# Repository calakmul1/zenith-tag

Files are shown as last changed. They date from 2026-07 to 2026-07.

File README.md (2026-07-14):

# Zenith Tag - NFC Flight Altitude Logger

Zenith Tag is a compact embedded altitude logger built around the NXP NHS3100 and Bosch BMP388.
It captures relative max flight altitude from barometric pressure and writes the result as an NFC URI record, so the value can be read by a phone with no wired interface.

<table align="center">
	<tr>
		<td align="center" valign="middle" width="74%">
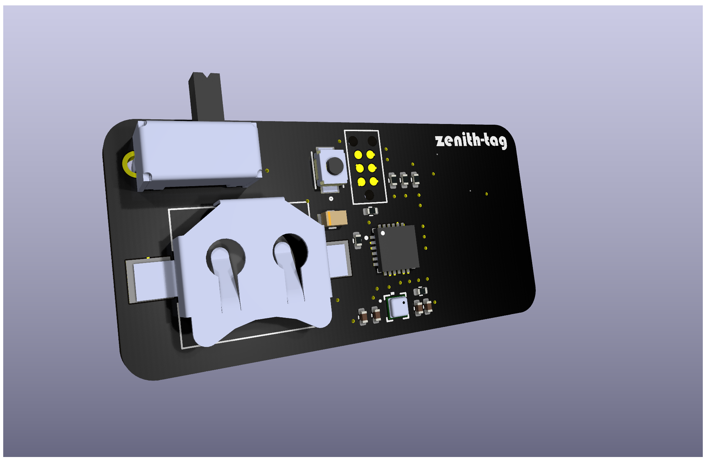
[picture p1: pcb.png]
PCB
			
		</td>
		<td align="center" valign="middle" width="26%">
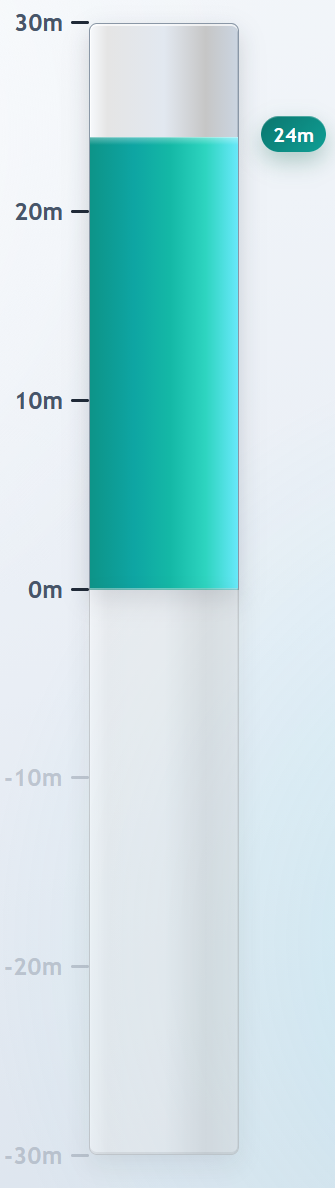
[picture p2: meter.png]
Altitude meter UI
			
		</td>
	</tr>
	<tr>
		<td align="center"><sub>PCB Layout</sub></td>
		<td align="center"><sub>Altitude Meter UI</sub></td>
	</tr>
</table>

## What This Repository Contains

This repository is split into three main parts:

- `hw/`: KiCad design files, custom libraries, 3D models, and datasheets
- `sw/`: NHS3100 firmware project (MCUXpresso style) and source modules
- `web/`: Vue 3 web app served from the NFC URI that visualises the recorded altitude

## High-Level Features

- BMP388 pressure and temperature acquisition over I2C
- Full BMP388 calibration and compensation implementation in firmware
- Relative altitude computation using barometric equation
- Push-button controlled measurement session
- LED status signaling (idle, actively measuring, and error indication)
- NFC Type-2 compatible NDEF URI payload written to NHS3100 shared memory
- Web app landing page that parses the height query parameter and renders an animated altitude bar

## Repository Structure

### Hardware (`hw/`)

- Main KiCad project files:
	- `hw/hw.kicad_sch`
	- `hw/hw.kicad_pcb`
	- `hw/hw.kicad_pro`
- Custom part libraries:
	- `hw/footprints/` and `hw/hw.pretty/` for footprint definitions
	- `hw/symbols/` for custom symbol definitions
	- `hw/models/` for STEP 3D models
- Engineering references:
	- `hw/datasheets/` for component PDFs and reference image files
	- `hw/calculations/NFC-Antenna-Calculation.xlsx` for antenna-related design calculations

### Firmware (`sw/`)

- Application source tree: `sw/src/`
- Core application entry point: `sw/src/main.c`
- Board and low-level init:
	- `sw/src/board/inc/board.h`
	- `sw/src/board/src/board.c`
- Functional components:
	- `sw/src/components/button/`
	- `sw/src/components/led/`
	- `sw/src/components/pressure/`
	- `sw/src/components/nfc/`
- Device/library code:
	- `sw/src/lib/lib_chip_nss/`
	- `sw/src/lib/startup/`

### Web App (`web/`)

A Vite + Vue 3 single-page app hosted at the NFC URI target.

- Entry point: `web/src/App.vue`
- Reads the `height` query parameter from the URL (e.g. `?height=12.34`)
- Renders an animated vertical bar showing the recorded altitude, clamped to ±30 m
- Styled with Bulma

To run locally:

```sh
cd web
npm install
npm run dev
```

To build for production:

```sh
npm run build
```

## Firmware Behavior

The main loop in `sw/src/main.c` follows this sequence:

1. Initialize board/peripherals and BMP388.
2. Wait for button press to start a measurement session.
3. Collect a short pre-takeoff pressure baseline (`PRE_TAKEOFF_MEASUREMENTS`).
4. Repeatedly sample pressure while session is active, tracking the minimum pressure reached.
5. End session with a second button press.
6. Compute signed relative altitude from both `pressure_min` and `pressure_max` versus baseline pressure, choose the larger magnitude, then apply a `-0.50 m` offset.
7. Store the measured value over NFC as a URI query parameter: `https://example.com/?height=<value>`.

Current default timing constants are defined in `sw/src/config.h`:

- Debounce: 5 ms
- Measurement interval: 20 ms
- LED toggle during active measurement: 500 ms
- Baseline sample count: 10

## Hardware/Firmware Interface Summary

- MCU: NXP NHS3100 (integrated NFC + Cortex-M0+)
- Pressure sensor: Bosch BMP388 on I2C address `0x77`
- Key pin usage in firmware:
	- `PIO0_1`: button input
	- `PIO0_2`: status LED output
	- `PIO0_4`: I2C SCL
	- `PIO0_5`: I2C SDA

## NFC Output Format

The NFC module (`sw/src/components/nfc/nfc.c`) writes a compact NDEF URI record into NHS3100 NFC shared memory.
The payload encodes a URL in this form: `https://example.com/?height=<value>`.

Example payload:

`https://example.com/?height=12.34`

## Build and Flash Notes

This project is structured like an MCUXpresso/Eclipse embedded project.

- Recommended workflow:
	- Import the `sw/` project into MCUXpresso IDE
	- Build using IDE-managed toolchain/configuration
	- Program/debug using LinkServer and the provided launch configuration
- Command-line makefiles are auto-generated and may contain absolute machine-specific paths in linker/library references.

## Included References

- Component datasheets and design references: `hw/datasheets/`

## Typical Use

1. Manufacture the PCB.
2. Configure GUI_BASE_URL in `config.h` with the URL of the web application that should open after the NFC tag is scanned.
3. Build and flash the firmware to the NHS3100 board.
4. Power on the tag and wait for idle-ready indication.
5. Press the button to start logging.
6. Press the button again to stop logging.
7. Tap a phone to the NFC antenna area — the phone opens the stored URI in a browser.
8. The web app reads the `height` query parameter and displays the recorded altitude.

---

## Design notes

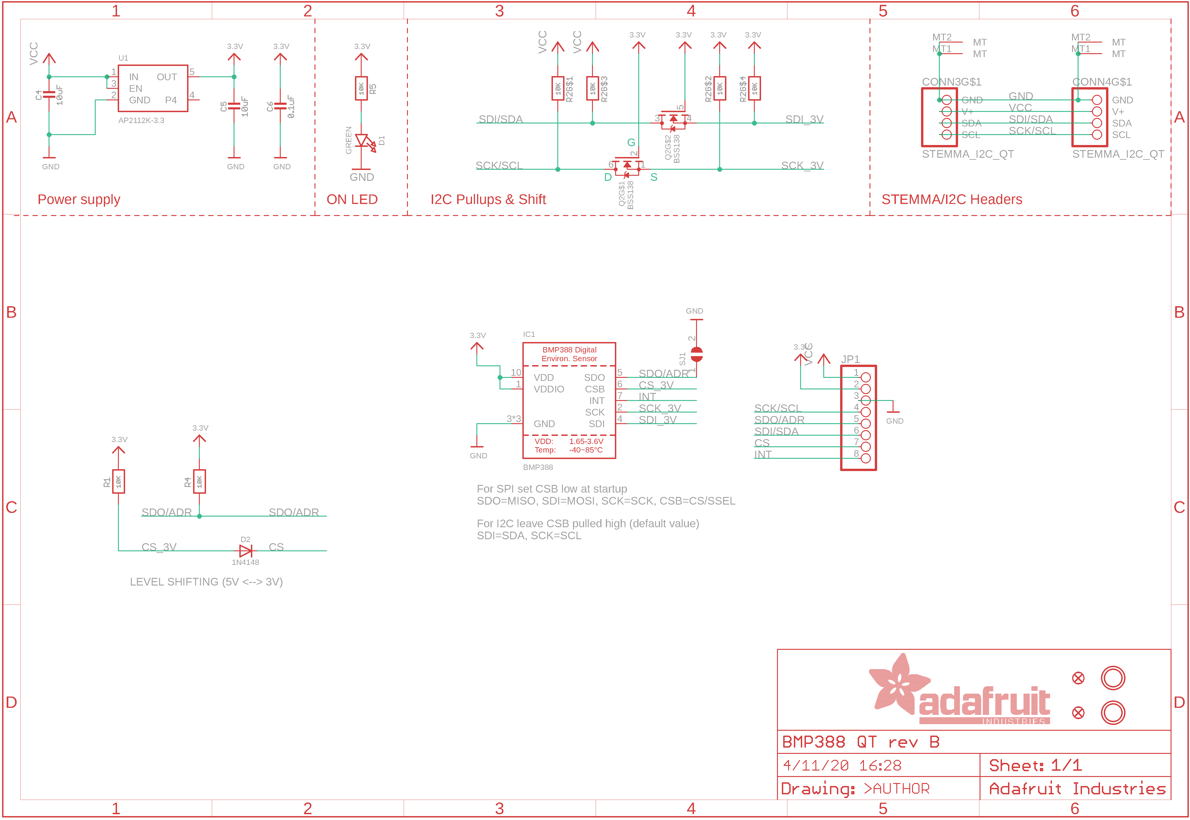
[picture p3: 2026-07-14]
hw/datasheets/sensors_BMP388_STEMMA_sch.png

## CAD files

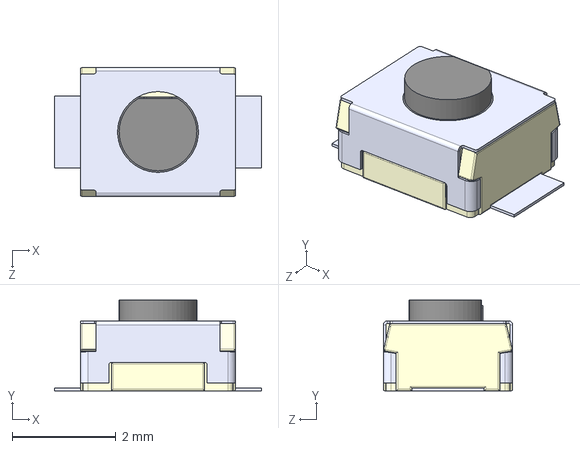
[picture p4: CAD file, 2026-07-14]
hw/models/B3U-1000P--3DModel-STEP-56544.STEP
4.00 x 1.75 x 2.50 mm

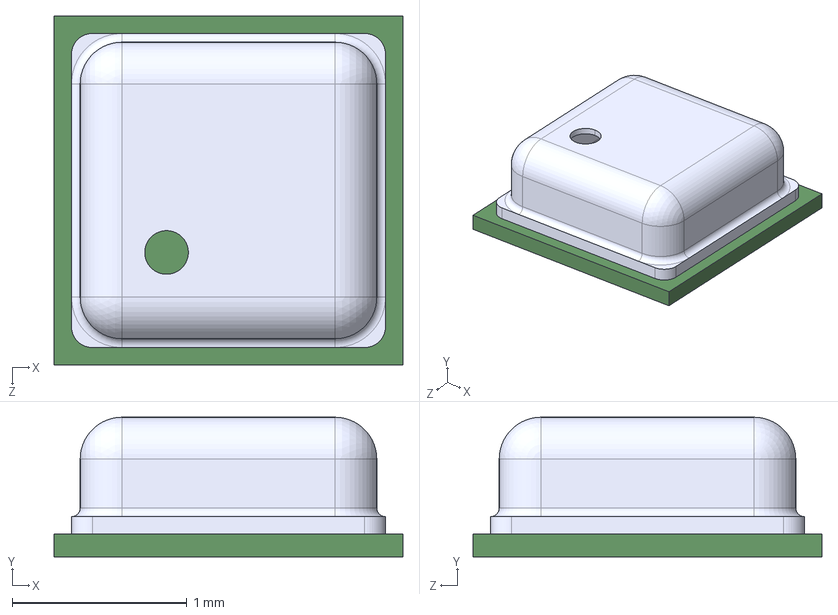
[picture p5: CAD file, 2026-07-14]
hw/models/BMP388--3DModel-STEP-56544.STEP
2.00 x 0.8 x 2.00 mm

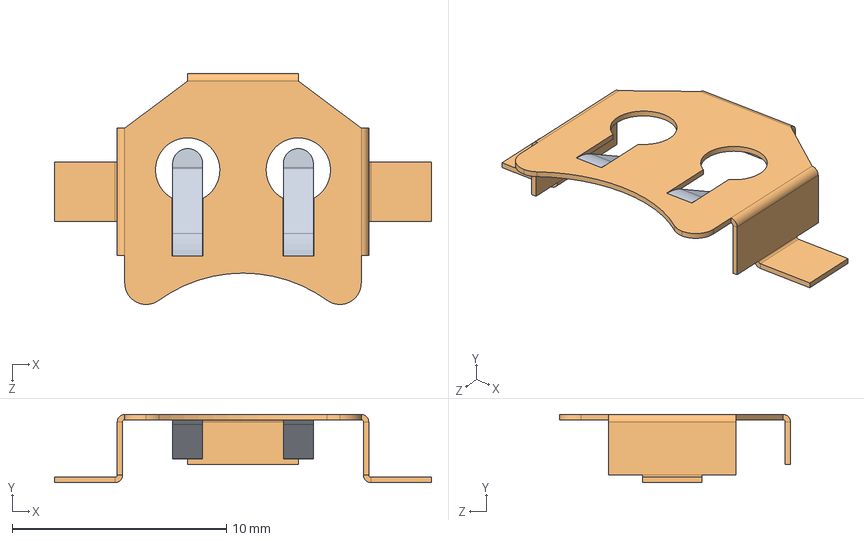
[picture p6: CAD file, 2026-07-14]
hw/models/BK870.step
17.6 x 3.18 x 10.8 mm

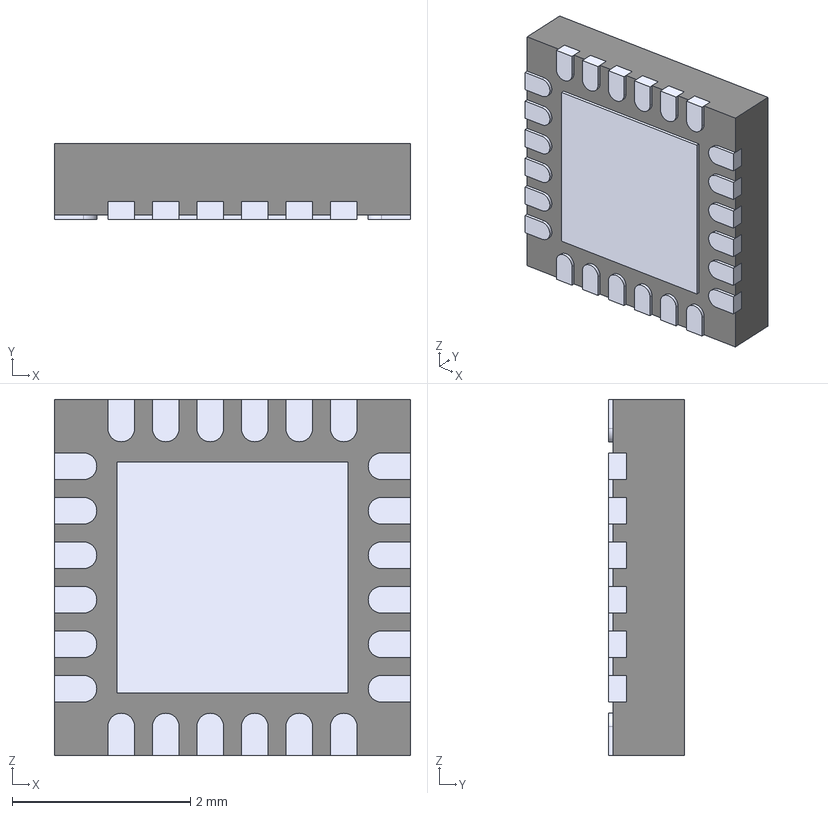
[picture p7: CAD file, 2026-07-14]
hw/models/NHS3100.step
4.00 x 0.85 x 4.00 mm
Body_Solid1
Body001_Solid1
Array_Solid1 x 6
Array001_Solid2 x 5
Body002_Solid1
Array002_Solid1 x 6
Array003_Solid2 x 5
Body003_Solid1
Body004_Solid1

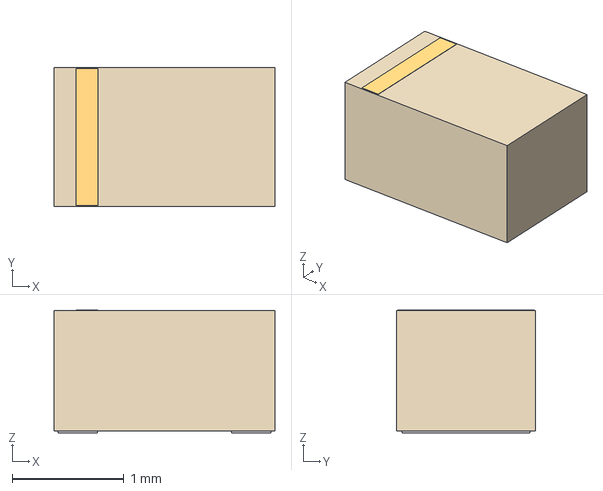
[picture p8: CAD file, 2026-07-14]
hw/models/LED_NCD0805R1_FNO.step
1.97 x 1.24 x 1.09 mm

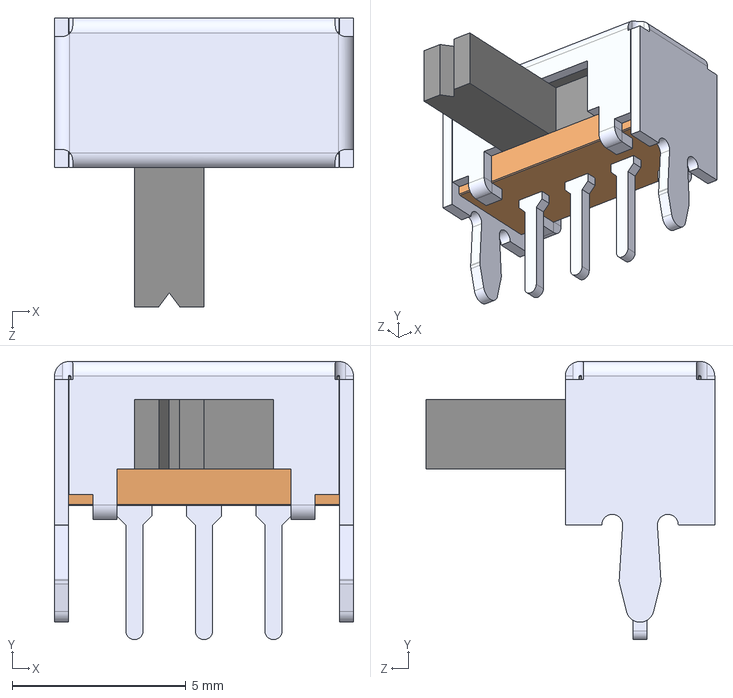
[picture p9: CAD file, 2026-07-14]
hw/models/SK12D07VG4.step
8.60 x 8.00 x 8.30 mm

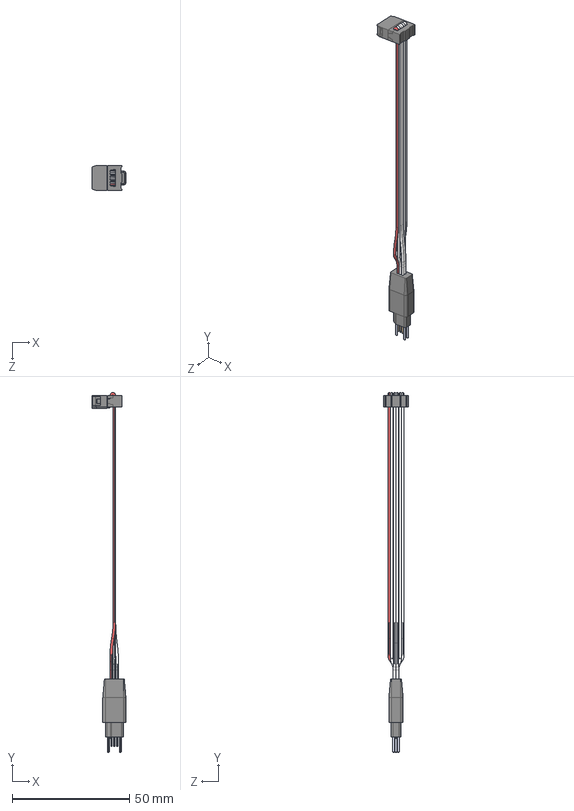
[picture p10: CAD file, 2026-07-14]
hw/models/TC2030-IDC-NL.step
14.5 x 153.6 x 10.7 mm

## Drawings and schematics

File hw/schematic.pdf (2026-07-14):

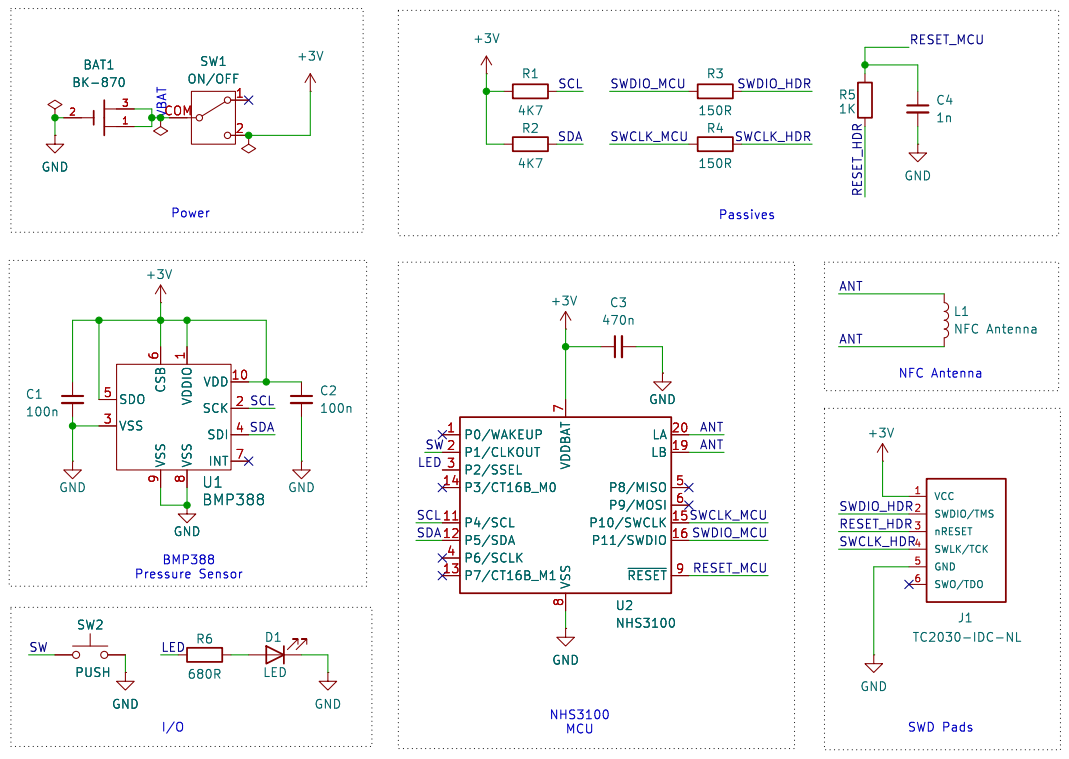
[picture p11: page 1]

Id: 1/1 Title: zenith-tag

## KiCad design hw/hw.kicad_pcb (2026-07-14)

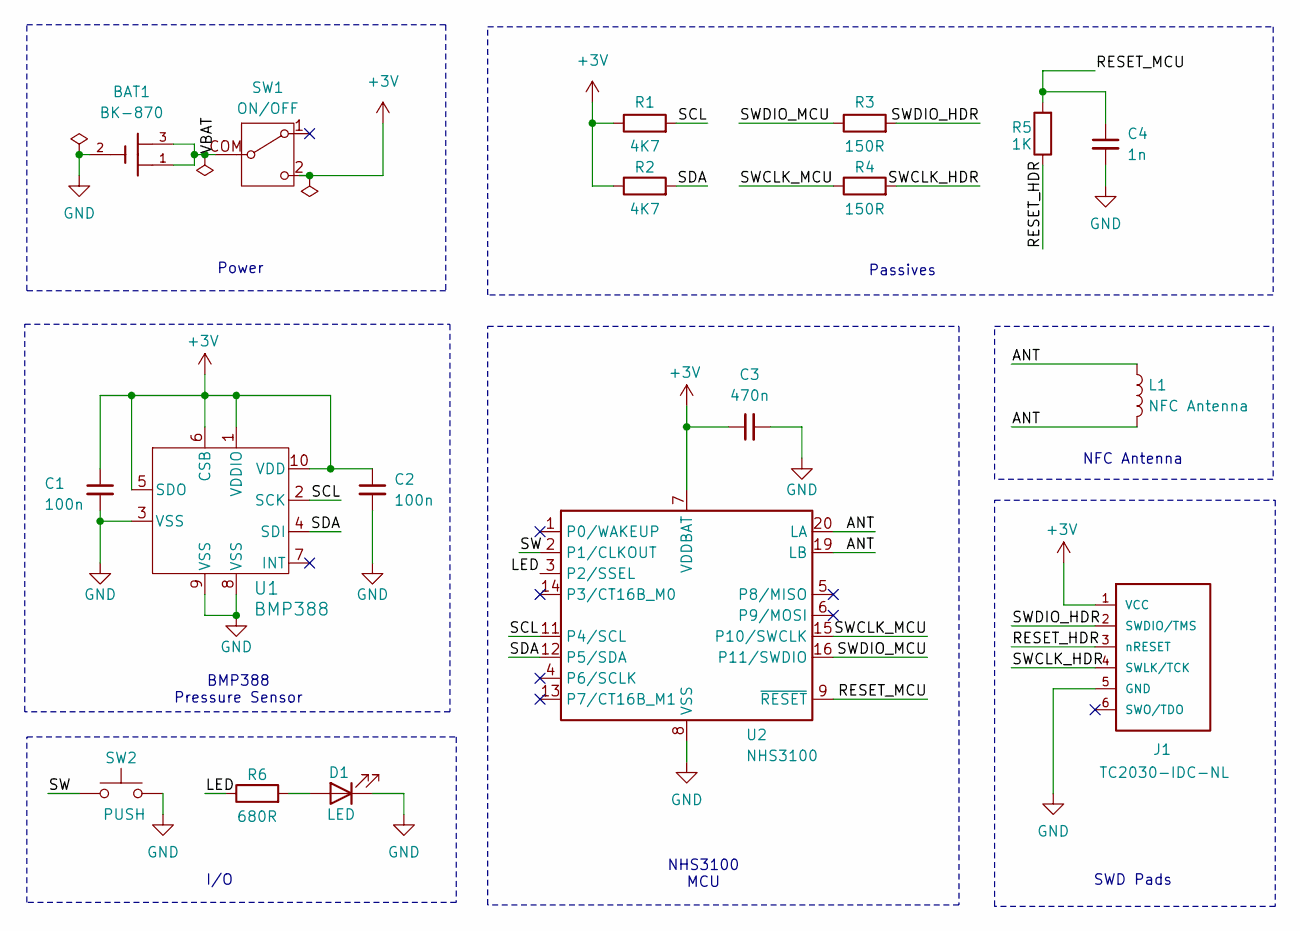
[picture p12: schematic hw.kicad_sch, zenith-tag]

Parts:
BAT1: BK-870; BK870; LCSC C6470567
C1: 100n; C_0402_1005Metric; LCSC C1525
C2: 100n; C_0402_1005Metric
C3: 470n; C_0402_1005Metric; LCSC C47339
C4: 1n; C_0402_1005Metric; LCSC C1523
D1: LED; LED_NCD0805R1_FNO; LCSC C84256
J1: TC2030-IDC-NL; TAG_TC2030-IDC-NL
L1: NFC Antenna; NFC_ANTENNA10x15
R1, R2: 4K7; R_0402_1005Metric; LCSC C25900
R3, R4: 150R; R_0402_1005Metric; LCSC C25082
R5: 1K; R_0402_1005Metric; LCSC C11702
R6: 680R; R_0402_1005Metric; LCSC C25130
SW1: ON/OFF; SK12D07VG4; LCSC C393937
SW2: PUSH; B3U-1000P_OMR; LCSC C231329
U1: BMP388; BMP388-QFN_BMP388_BOS; LCSC C779278
U2: NHS3100; NHS3100-QFN50P400X400X100-25N; LCSC C2654844

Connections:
+3V: C1.1, C2.1, C3.1, J1.1 (VCC), R1.1, R2.1, SW1.2 (C), U1.1 (VDDIO), U1.5 (SDO), U1.6 (CSB), U1.10 (VDD), U2.7 (VDDBAT)
/ANT: L1.1, L1.2, U2.19 (LB), U2.20 (LA)
/LED: R6.1, U2.3 (P2/SSEL)
/RESET_HDR: J1.3 (nRESET), R5.1
/RESET_MCU: C4.1, R5.2, U2.9 (~RESET)
/SCL: R1.2, U1.2 (SCK), U2.11 (P4/SCL)
/SDA: R2.2, U1.4 (SDI), U2.12 (P5/SDA)
/SW: SW2.1, U2.2 (P1/CLKOUT)
/SWCLK_HDR: J1.4 (SWLK/TCK), R4.2
/SWCLK_MCU: R4.1, U2.15 (P10/SWCLK)
/SWDIO_HDR: J1.2 (SWDIO/TMS), R3.2
/SWDIO_MCU: R3.1, U2.16 (P11/SWDIO)
/VBAT: BAT1.1, BAT1.3, SW1.COM (B)
GND: BAT1.2, C1.2, C2.2, C3.2, C4.2, D1.1 (K), J1.5 (GND), SW2.2, U1.3 (VSS), U1.8 (VSS), U1.9 (VSS), U2.8 (VSS), U2.17 (VSS), U2.18 (VSS), U2.21 (VSS), U2.22 (VSS), U2.23 (VSS), U2.24 (VSS), U2.25 (VSS)
unnamed: D1.2 (A), R6.2

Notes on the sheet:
SWD Pads
I/O
Power
NHS3100 MCU
NFC Antenna
Passives
BMP388 Pressure Sensor

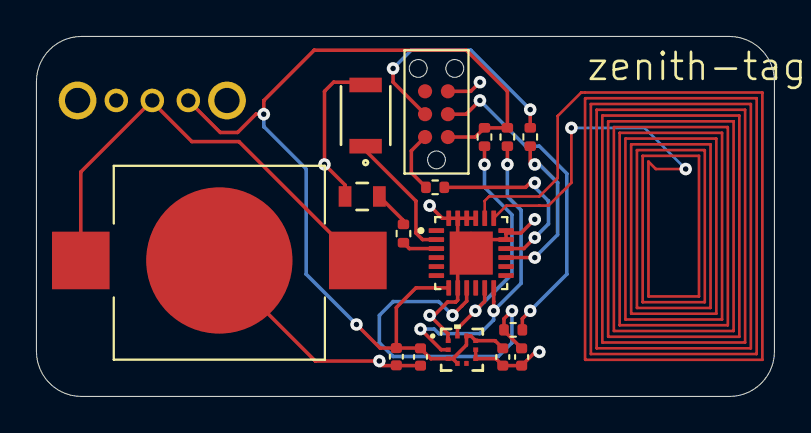
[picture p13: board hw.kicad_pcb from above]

Board: 2 copper layers, 41.0 x 20.0 mm, 18 parts (0 on the bottom side), 15 nets.

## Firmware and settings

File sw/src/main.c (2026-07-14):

#include <stdint.h>

#include "config.h"
#include "board/inc/board.h"
#include "components/button/button.h"
#include "components/led/led.h"
#include "components/pressure/pressure.h"
#include "components/nfc/nfc.h"

int main(void)
{
    Board_Init();

    // This wait call is intended to avoid bricking the IC. Don't remove.
    Chip_Clock_System_BusyWait_ms(1000);

    bool success;
    success = Peripherals_Init();

    if (!success)
    {
        LED_Error();
        return -1;
    }

    Chip_Clock_System_BusyWait_ms(1000);

    LED_On();

    while (true)
    {
        if (Button_Check_Pressed() == true)
        {
            Pressure_Start_Read();

            float pressure_current = 0.0f;
            float temperature_current = 0.0f;
            float pressure_sum = 0.0f;

            for (int i = 0; i < PRE_TAKEOFF_MEASUREMENTS; i++)
            {
                Chip_Clock_System_BusyWait_ms(MEASUREMENT_INTERVAL_MS);
                Pressure_Read(&pressure_current, &temperature_current);
                pressure_sum += pressure_current;
            }

            float pressure_baseline = pressure_sum / (float)PRE_TAKEOFF_MEASUREMENTS;
            float pressure_max = pressure_baseline;
            float pressure_min = pressure_baseline;

            uint32_t led_timer = 0U;

            while (true)
            {
                Chip_Clock_System_BusyWait_ms(MEASUREMENT_INTERVAL_MS);

                Pressure_Read(&pressure_current, &temperature_current);

                if (pressure_current < pressure_min)
                {
                    pressure_min = pressure_current;
                }

                if (pressure_current > pressure_max)
                {
                    pressure_max = pressure_current;
                }

                led_timer += MEASUREMENT_INTERVAL_MS;

                if (led_timer >= LED_TOGGLE_INTERVAL_MS)
                {
                    LED_Toggle();
                    led_timer = 0;
                }

                if (Button_Check_Pressed() == true)
                {
                    break;
                }
            }

            float h_up = Pressure_Calculate_Height(pressure_min, pressure_baseline);
            float h_down = Pressure_Calculate_Height(pressure_baseline, pressure_max);

            float delta_h;

            if (h_up > h_down)
            {
                delta_h = h_up;
            }
            else
            {
                delta_h = -h_down;
            }

            delta_h -= 0.50f;

            NFC_Store_Flight_Height(delta_h);

            Pressure_End_Read();

            LED_On();
            Chip_Clock_System_BusyWait_ms(200);
        }
    }

    return 0;
}

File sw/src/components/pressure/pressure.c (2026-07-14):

#include <math.h>
#include <errno.h>
#include <float.h>

#include "lib_chip_nss/inc/chip.h"

#include "pressure.h"

#include "components/led/led.h"
#include "components/nfc/nfc.h"

/** @brief I2C address of the BMP388 pressure sensor. */
#define BMP388 0x77

/**
 * @brief Raw calibration coefficients as read directly from the BMP388 registers.
 *
 * This structure maps the unscaled integer coefficients stored in the BMP388
 * non-volatile memory (registers 0x31–0x45). These coefficients are device-specific
 * and must be converted into floating-point form before use in compensation
 * formulas.
 *
 * @see bmp388_calib_f32_t
 */
typedef struct
{
    uint16_t par_t1; /**< Temperature coefficient T1 (unsigned, LSB = 2⁻⁸). */
    uint16_t par_t2; /**< Temperature coefficient T2 (unsigned, LSB = 2⁻³⁰). */
    int8_t par_t3;   /**< Temperature coefficient T3 (signed, LSB = 2⁻⁴⁸). */
    int16_t par_p1;  /**< Pressure coefficient P1 (signed, LSB = 2⁻²⁰). */
    int16_t par_p2;  /**< Pressure coefficient P2 (signed, LSB = 2⁻²⁹). */
    int8_t par_p3;   /**< Pressure coefficient P3 (signed, LSB = 2⁻³²). */
    int8_t par_p4;   /**< Pressure coefficient P4 (signed, LSB = 2⁻³⁷). */
    uint16_t par_p5; /**< Pressure coefficient P5 (unsigned, LSB = 2⁻³). */
    uint16_t par_p6; /**< Pressure coefficient P6 (unsigned, LSB = 2⁻⁶). */
    int8_t par_p7;   /**< Pressure coefficient P7 (signed, LSB = 2⁻⁸). */
    int8_t par_p8;   /**< Pressure coefficient P8 (signed, LSB = 2⁻¹⁵). */
    int16_t par_p9;  /**< Pressure coefficient P9 (signed, LSB = 2⁻⁴⁸). */
    int8_t par_p10;  /**< Pressure coefficient P10 (signed, LSB = 2⁻⁴⁸). */
    int8_t par_p11;  /**< Pressure coefficient P11 (signed, LSB = 2⁻⁶⁵). */
} bmp388_calib_t;

/**
 * @brief Floating-point calibration coefficients for compensated measurements.
 *
 * This structure stores the scaled calibration coefficients converted from
 * @ref bmp388_calib_t using the formulas provided in the BMP388 datasheet.
 * These parameters are used in the temperature and pressure compensation functions.
 */
typedef struct
{
    float par_t1;  /**< Temperature coefficient T1 (scaled). */
    float par_t2;  /**< Temperature coefficient T2 (scaled). */
    float par_t3;  /**< Temperature coefficient T3 (scaled). */
    float par_p1;  /**< Pressure coefficient P1 (scaled). */
    float par_p2;  /**< Pressure coefficient P2 (scaled). */
    float par_p3;  /**< Pressure coefficient P3 (scaled). */
    float par_p4;  /**< Pressure coefficient P4 (scaled). */
    float par_p5;  /**< Pressure coefficient P5 (scaled). */
    float par_p6;  /**< Pressure coefficient P6 (scaled). */
    float par_p7;  /**< Pressure coefficient P7 (scaled). */
    float par_p8;  /**< Pressure coefficient P8 (scaled). */
    float par_p9;  /**< Pressure coefficient P9 (scaled). */
    float par_p10; /**< Pressure coefficient P10 (scaled). */
    float par_p11; /**< Pressure coefficient P11 (scaled). */
    float t_lin;   /**< Linearized temperature value (°C) used in pressure compensation. */
} bmp388_calib_f32_t;

/**
 * @brief Global instance of BMP388 floating-point calibration data.
 *
 * This structure holds the converted and scaled calibration coefficients
 * for the currently active BMP388 sensor. It is initialized during
 * @ref Pressure_Load_Calibration and subsequently used by
 * @ref Pressure_Compensate_Temperature and @ref Pressure_Compensate_Pressure
 * to compute compensated temperature and pressure readings.
 */
bmp388_calib_f32_t calib_float;

/**
 * @defgroup POW2_Constants Precomputed power-of-two constants
 * @brief Floating-point powers of two for fast scaling operations.
 * @{
 */
#define POW2_3 0x1p3f   /**< 2³  = 8.0f */
#define POW2_6 0x1p6f   /**< 2⁶  = 64.0f */
#define POW2_8 0x1p8f   /**< 2⁸  = 256.0f */
#define POW2_14 0x1p14f /**< 2¹⁴ = 16,384.0f */
#define POW2_15 0x1p15f /**< 2¹⁵ = 32,768.0f */
#define POW2_20 0x1p20f /**< 2²⁰ = 1,048,576.0f */
#define POW2_29 0x1p29f /**< 2²⁹ = 536,870,912.0f */
#define POW2_30 0x1p30f /**< 2³⁰ = 1,073,741,824.0f */
#define POW2_32 0x1p32f /**< 2³² = 4,294,967,296.0f */
#define POW2_37 0x1p37f /**< 2³⁷ ≈ 1.37e11f */
#define POW2_48 0x1p48f /**< 2⁴⁸ ≈ 2.81e14f */
#define POW2_65 0x1p65f /**< 2⁶⁵ ≈ 3.69e19f */
/** @} */

static bool Pressure_Detect_Sensor();
static bool Pressure_Load_Calibration();
static bool Pressure_Configure();
static float Pressure_Compensate_Temperature(uint32_t temperature_raw);
static float Pressure_Compensate_Pressure(uint32_t pressure_raw);

bool Pressure_Init()
{
    bool success = Pressure_Detect_Sensor();

    if (!success)
        return false;

    success = Pressure_Load_Calibration();

    if (!success)
        return false;

    success = Pressure_Configure();

    if (!success)
        return false;

    return true;
}

bool Pressure_Start_Read()
{
    uint8_t i2c_command[2];
    int i2c_result;

    uint8_t bmp_error_i2c_reg = 0x02;
    uint8_t bmp_error;

    i2c_command[0] = 0x1B;
    i2c_command[1] = 0x33; // Enable pressure and temperature sensors in normal mode, see
                           // chapter 4.3.16 of the BMP388 datasheet.

    i2c_result = Chip_I2C_MasterSend(I2C0, BMP388, i2c_command, 2);

    Chip_I2C_MasterCmdRead(I2C0, BMP388, &bmp_error_i2c_reg, &bmp_error, 1);

    if (i2c_result == 2 && bmp_error == 0x00)
    {
        // Success
    }
    else
    {
        LED_Error();
        return false;
    }

    return true;
}

bool Pressure_End_Read()
{
    uint8_t i2c_command[2];
    int i2c_result;

    uint8_t bmp_error_i2c_reg = 0x02;
    uint8_t bmp_error;

    i2c_command[0] = 0x1B;
    i2c_command[1] = 0x00; // Disable pressure and temperature sensors and go to sleep mode, see
                           // chapter 4.3.16 of the BMP388 datasheet.

    i2c_result = Chip_I2C_MasterSend(I2C0, BMP388, i2c_command, 2);

    Chip_I2C_MasterCmdRead(I2C0, BMP388, &bmp_error_i2c_reg, &bmp_error, 1);

    if (i2c_result == 2 && bmp_error == 0x00)
    {
        // Success
    }
    else
    {
        LED_Error();
        return false;
    }

    return true;
}

bool Pressure_Read(float *pressure, float *temperature)
{
    uint8_t i2c_reg = 0x04;
    uint8_t i2c_data[6];
    int i2c_result;

    uint8_t bmp_error_i2c_reg = 0x02;
    uint8_t bmp_error;

    i2c_result = Chip_I2C_MasterCmdRead(I2C0, BMP388, &i2c_reg, &i2c_data[0], 6);

    Chip_I2C_MasterCmdRead(I2C0, BMP388, &bmp_error_i2c_reg, &bmp_error, 1);

    if (i2c_result == 6 && bmp_error == 0x00)
    {
        // Success
    }
    else
    {
        LED_Error();
        return false;
    }

    uint32_t pressure_raw =
        ((uint32_t)i2c_data[2] << 16) | ((uint32_t)i2c_data[1] << 8) | i2c_data[0];
    uint32_t temperature_raw =
        ((uint32_t)i2c_data[5] << 16) | ((uint32_t)i2c_data[4] << 8) | i2c_data[3];

    *temperature = Pressure_Compensate_Temperature(temperature_raw);
    *pressure = Pressure_Compensate_Pressure(pressure_raw);

    return true;
}
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
